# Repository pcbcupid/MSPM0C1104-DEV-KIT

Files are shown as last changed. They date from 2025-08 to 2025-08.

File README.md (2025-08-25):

# MSPM0C1104-DEV-KIT / INDUSTRIAL TEMPERATURE/HUMIDITY SENSOR MODULE WITH RS485 OUTPUT 
pcbcupid-gsense-gsi003

This design can be used as both exploration boards for worlds tiniest controller and also as a stand alone sensor module 
which can measure temperature and humidity with very high prescision. 

You can read more about it here : [link](https://learn.pcbcupid.com/boards/g-sense/hdc3020-rs485)

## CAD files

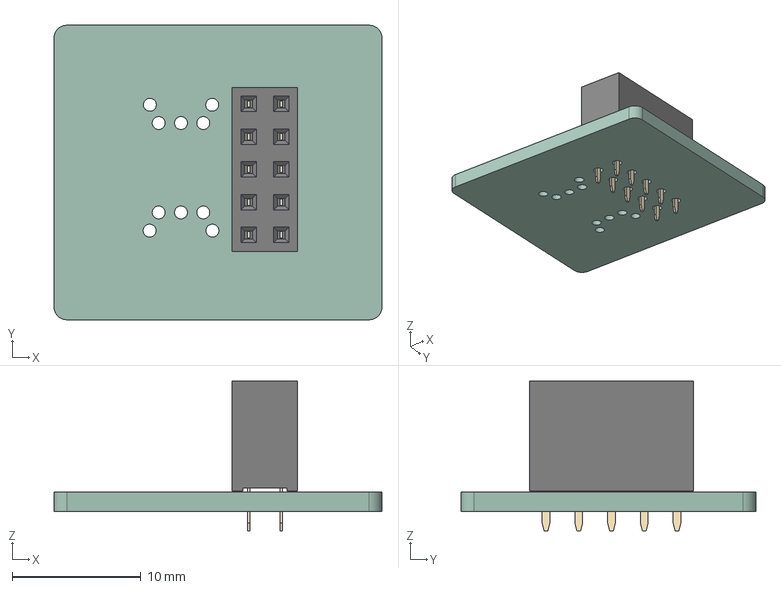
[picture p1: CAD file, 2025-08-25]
MSPM0C1104_JTAG_PROGRAMMER/MSPM0C1104_JTAG_PROGRAMMER.step
25.4 x 22.8 x 11.6 mm
PinSocket_2x05_P2.54mm_Vertical
MSPM0C_CON_PROG_V2_PCB

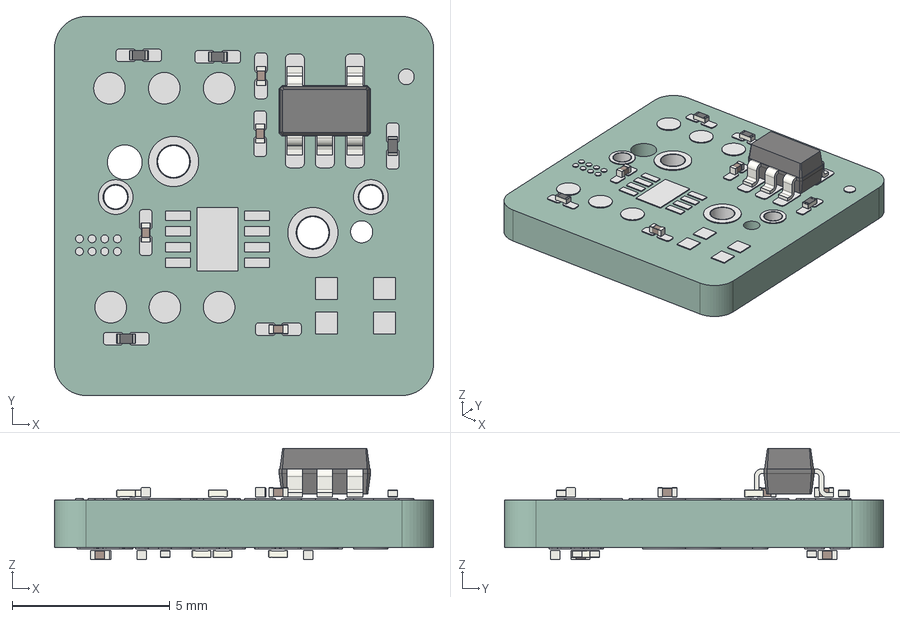
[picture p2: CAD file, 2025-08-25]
MSPMOC1104_NON-RS485-DBGA/MSPMOC1104_NON-RS485-DBGA.step
12.0 x 12.0 x 3.53 mm
C_0201_0603Metric x 8
R_0201_0603Metric x 8
SOT-23-5
MSPMOC1104_DBGA_V2_pad
MSPMOC1104_DBGA_V2_PCB

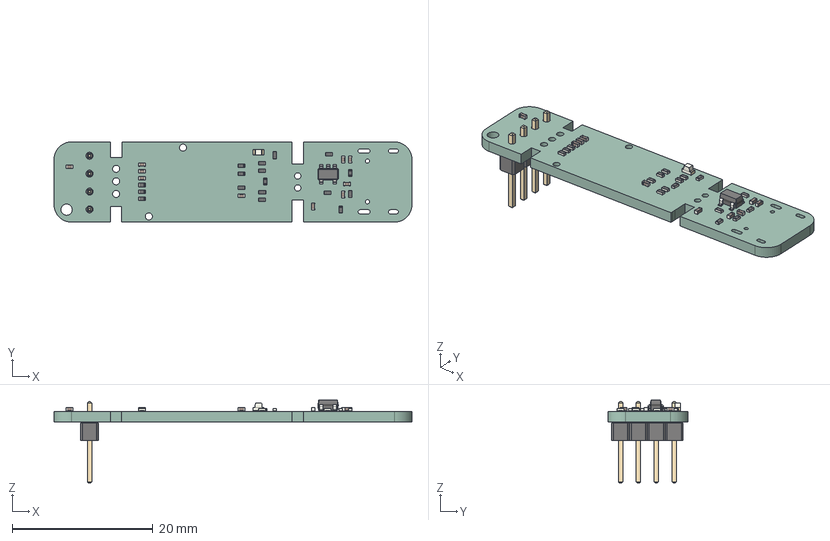
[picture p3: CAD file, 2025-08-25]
MSPMOC1104_RS485/MSPMOC1104_RS485.step
50.8 x 11.4 x 11.8 mm
R_0402_1005Metric x 17
C_0402_1005Metric x 10
LED_0603_1608Metric
SOT-23-5
PinHeader_1x04_P2.54mm_Vertical
MSPMOC1104_RS485_V2_PCB

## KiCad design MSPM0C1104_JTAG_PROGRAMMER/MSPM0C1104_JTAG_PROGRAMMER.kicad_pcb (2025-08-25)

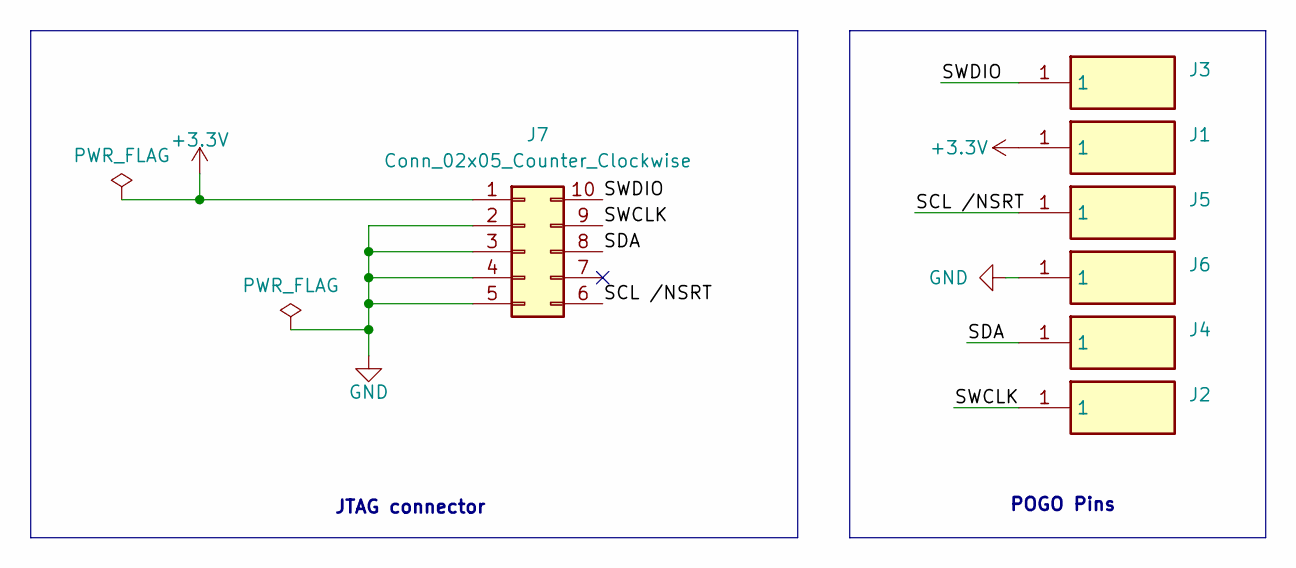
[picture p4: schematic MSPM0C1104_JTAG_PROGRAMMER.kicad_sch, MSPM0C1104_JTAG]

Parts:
J1, J2, J3, J4, J5, J6: 0950-0-15-20-64-14-11-0; TestPoint_THTPad_D1.5mm_Drill1mm; Mouser Part Number 575-950015206414110
J7: Conn_02x05_Counter_Clockwise; PinSocket_2x05_P2.54mm_Vertical

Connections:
+3.3V: J1.1, J7.1
/SCL /NSRT: J5.1, J7.6
/SDA: J4.1, J7.8
/SWCLK: J2.1, J7.9
/SWDIO: J3.1, J7.10
GND: J6.1, J7.2, J7.3, J7.4, J7.5

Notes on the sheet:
POGO Pins
JTAG connector

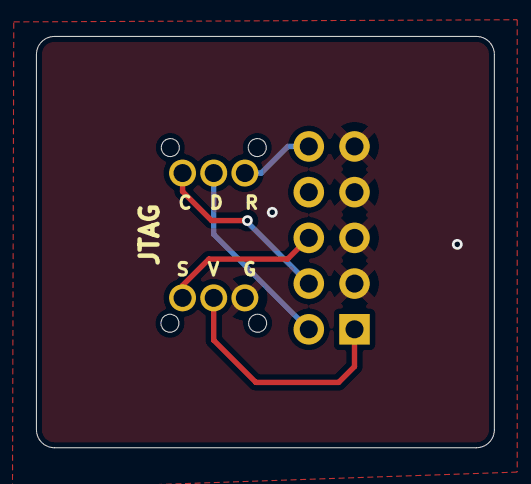
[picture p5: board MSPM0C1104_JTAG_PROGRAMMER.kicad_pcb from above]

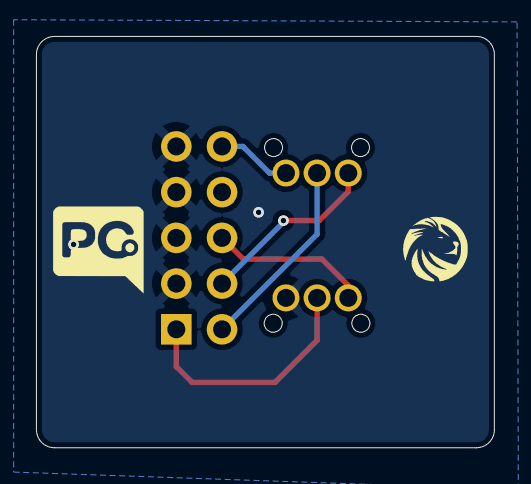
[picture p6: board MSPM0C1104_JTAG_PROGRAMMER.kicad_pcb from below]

Board: 2 copper layers, 25.4 x 22.8 mm, 7 parts (6 on the bottom side), 6 nets.

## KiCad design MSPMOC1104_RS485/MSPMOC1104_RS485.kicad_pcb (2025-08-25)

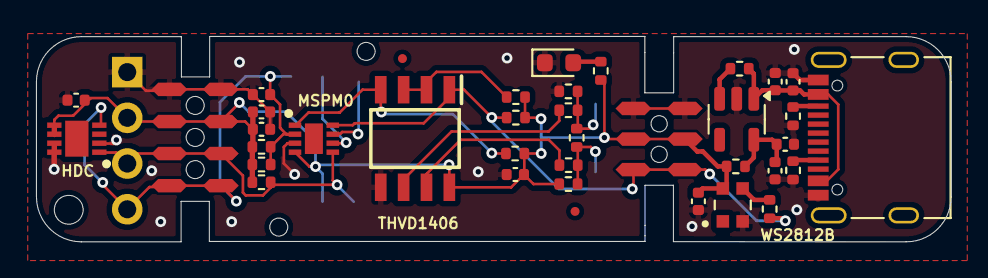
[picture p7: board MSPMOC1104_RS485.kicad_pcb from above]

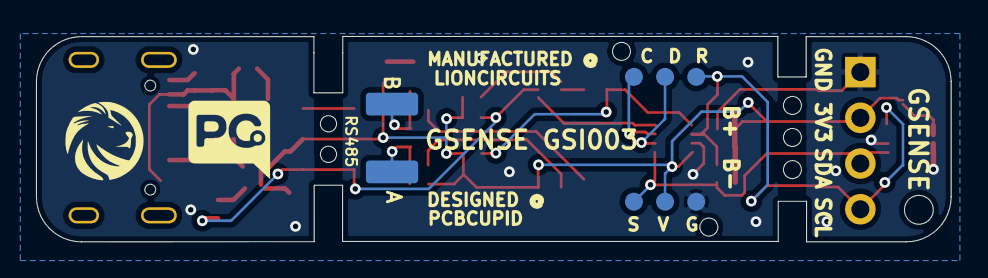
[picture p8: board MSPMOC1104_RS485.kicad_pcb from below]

Board: 2 copper layers, 50.8 x 11.4 mm, 58 parts (10 on the bottom side), 20 nets.

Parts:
C1, C2, C3, C6, C7: 0.1uF; C_0402_1005Metric
C4: 10nF; C_0402_1005Metric
C5: 10uF; C_0402_1005Metric
C8, C9, C10: 10uf; C_0402_1005Metric
D2: LED; LED_0603_1608Metric
GND: TestPoint_Pad_1.0x1.0mm
GND#2, GND#3, GND#4, GND#5, GND#6, GND#7, GND#8, GND#9, GND#10, GND#11, GND#12, GND#13, GND#14: TestPoint_Pad_1.0x1.0mm
IC1: HDC3020DEFR
IC2: THVD1426DR
J1, J2, J3, J4, J5, J6: 0950-0-15-20-64-14-11-0; TestPoint_Pad_D1.0mm
J7: USB_C_Receptacle_USB2.0_16P; USB_C_Receptacle_Palconn_UTC16-G
J8: Conn_01x02_Pin; conn_1_2
J9: Conn_01x04; PinHeader_1x04_P2.54mm_Vertical
Lion_circuits-1: LOGO; Lion_circuits_Logo
PCB_CUBID-1: LOGO; PCB_CUBID
R1: 220R; R_0402_1005Metric
R2, R3: 4.7K; R_0402_1005Metric
R4, R6: 5.1k; R_0402_1005Metric
R5: 47K; R_0402_1005Metric
R7, R8, R9, R12, R14, R17: 4.7k; R_0402_1005Metric
R10, R11: 100; R_0402_1005Metric
R13: 120E; R_0402_1005Metric
R15: 100K; R_0402_1005Metric
R16: 0R; R_0402_1005Metric
U1: WS2812-2020; LED_WS2812-2020
U2: MSPM0C1104SDSGR
U3: AP2112K-3.3v; SOT-23-5

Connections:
+3.3V: C1.1, C2.1, C3.1, C5.1, C7.1, GND.1, GND#7.1, GND#8.1, GND#10.1, IC1.5 (VDD), IC1.6 (~RESET), IC2.8 (VCC), J1.1, J9.2, R2.1, R3.1, R5.1, R7.1, R8.2, R9.1, R12.2, R16.1, R17.2, U1.4 (VDD), U2.4 (VDD)
/SCL /NSRT: C4.1, GND#11.1, GND#13.1, IC1.4 (SCL), J2.1, J9.4, R3.2, R5.2, U2.2 (PA1/NRST)
/SDA: GND#2.1, GND#14.1, IC1.1 (SDA), J6.1, J9.3, R2.2, U2.5 (PA0)
/SWCLK: J5.1, U2.7 (PA20/A6/SWCLK)
/SWDIO: J3.1, U2.6 (PA19/SWDIO)
/VBUS: C6.1, C10.1, J7.A4 (VBUS), J7.A9 (VBUS), J7.B4 (VBUS), J7.B9 (VBUS), R15.1, U3.1 (VIN)
/cc1: J7.A5 (CC1), R4.1
/cc2: J7.B5 (CC2), R6.1
/led: R1.2, U1.3 (DI)
/pa24: GND#6.1, GND#9.1, IC2.1 (R), R1.1, R9.2, U2.8 (PA24/A3)
/pa27: IC2.4 (D), R8.1, U2.1 (PA27/A0)
/padA: IC2.7 (B), R10.1
/padB: IC2.6 (A), R11.1
/pasA: J8.1, R10.2, R12.1, R13.2
/pasB: J8.2, R11.2, R13.1, R14.2
/rs: IC2.2 (~RE), IC2.3 (~SHDN), R7.2
GND: C1.2, C2.2, C3.2, C4.2, C5.2, C6.2, C7.2, C8.2, C9.2, C10.2, D2.1 (K), GND#3.1, GND#4.1, GND#5.1, GND#12.1, IC1.2 (ADDR), IC1.7 (ADDR1), IC1.8 (GND), IC2.5 (GND), J4.1, J7.A1 (GND), J7.A12 (GND), J7.B1 (GND), J7.B12 (GND), J9.1, R4.2, R6.2, R14.1, U1.2 (GND), U2.3 (VSS), U3.2 (GND)
unnamed: D2.2 (A), R17.1
unnamed: R15.2, U3.3 (EN)
unnamed: C8.1, C9.1, R16.2, U3.5 (VOUT)

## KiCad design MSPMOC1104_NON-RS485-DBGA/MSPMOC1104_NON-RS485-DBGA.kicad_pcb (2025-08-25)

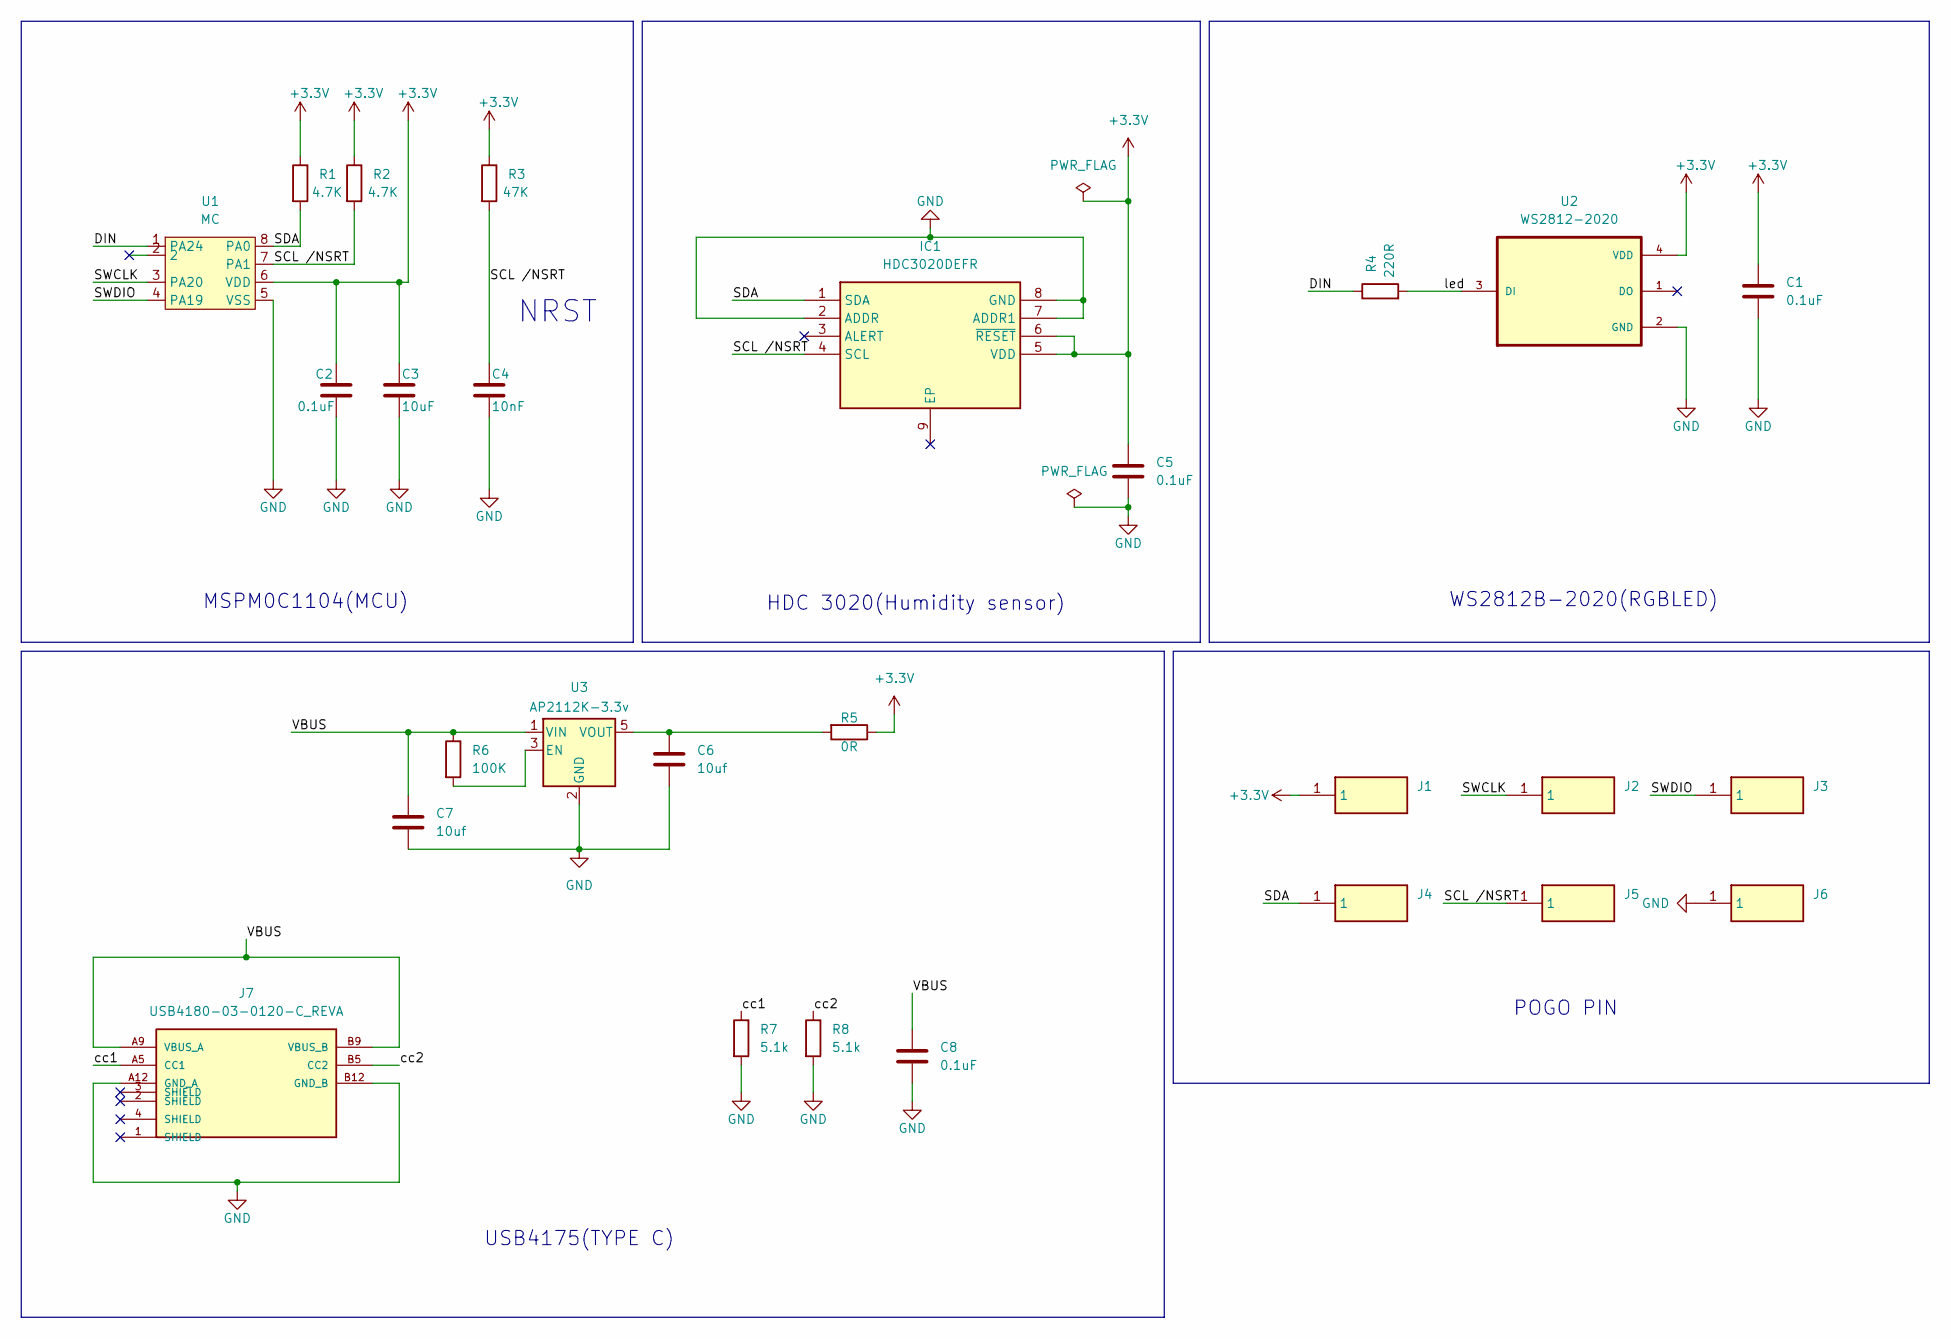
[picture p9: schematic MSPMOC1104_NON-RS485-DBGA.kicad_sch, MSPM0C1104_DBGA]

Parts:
C1, C2, C5, C8: 0.1uF; C_0201_0603Metric_Pad0.64x0.40mm_HandSolder
C3: 10uF; C_0201_0603Metric_Pad0.64x0.40mm_HandSolder
C4: 10nF; C_0201_0603Metric_Pad0.64x0.40mm_HandSolder
C6, C7: 10uf; C_0201_0603Metric_Pad0.64x0.40mm_HandSolder
IC1: HDC3020DEFR; Mouser Part Number 595-HDC3020DEFR
J1, J2, J3, J4, J5, J6: 0950-0-15-20-64-14-11-0; TestPoint_Pad_D1.0mm; Mouser Part Number 575-950015206414110
J7: USB4180-03-0120-C_REVA; USB4180030120C; PARTREV A; DigiKey_Part_Number 2073-USB4180-03-0120-CTR-ND
R1, R2: 4.7K; R_0201_0603Metric_Pad0.64x0.40mm_HandSolder
R3: 47K; R_0201_0603Metric_Pad0.64x0.40mm_HandSolder
R4: 220R; R_0201_0603Metric_Pad0.64x0.40mm_HandSolder
R5: 0R; R_0201_0603Metric_Pad0.64x0.40mm_HandSolder
R6: 100K; R_0201_0603Metric_Pad0.64x0.40mm_HandSolder
R7, R8: 5.1k; R_0201_0603Metric_Pad0.64x0.40mm_HandSolder
U1: MC; MCU_TI_MSPM0C1104
U2: WS2812-2020; LED_WS2812-2020; PARTREV V1.3
U3: AP2112K-3.3v; SOT-23-5

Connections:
+3.3V: C1.1, C2.1, C3.1, C5.1, IC1.5 (VDD), IC1.6 (~RESET), J1.1, R1.1, R2.1, R3.1, R5.1, U1.6 (VDD), U2.4 (VDD)
/DIN: R4.1, U1.1 (PA24)
/SCL /NSRT: C4.1, IC1.4 (SCL), J5.1, R2.2, R3.2, U1.7 (PA1)
/SDA: IC1.1 (SDA), J4.1, R1.2, U1.8 (PA0)
/SWCLK: J2.1, U1.3 (PA20)
/SWDIO: J3.1, U1.4 (PA19)
/VBUS: C7.1, C8.1, J7.A9 (VBUS_A), J7.B9 (VBUS_B), R6.1, U3.1 (VIN)
/cc1: J7.A5 (CC1), R7.1
/cc2: J7.B5 (CC2), R8.1
/led: R4.2, U2.3 (DI)
GND: C1.2, C2.2, C3.2, C4.2, C5.2, C6.2, C7.2, C8.2, IC1.2 (ADDR), IC1.7 (ADDR1), IC1.8 (GND), J6.1, J7.A12 (GND_A), J7.B12 (GND_B), R7.2, R8.2, U1.5 (VSS), U2.2 (GND), U3.2 (GND)
unnamed: R6.2, U3.3 (EN)
unnamed: C6.1, R5.2, U3.5 (VOUT)

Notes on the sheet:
POGO PIN
USB4175(TYPE C)
NRST
HDC 3020(Humidity sensor)
WS2812B-2020(RGBLED)
MSPM0C1104(MCU)

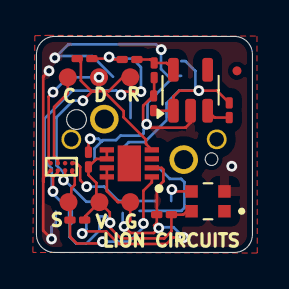
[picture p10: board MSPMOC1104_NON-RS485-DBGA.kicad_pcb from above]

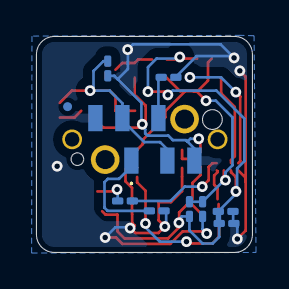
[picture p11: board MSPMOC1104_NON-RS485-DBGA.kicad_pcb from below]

Board: 2 copper layers, 12.0 x 12.0 mm, 27 parts (9 on the bottom side), 13 nets.

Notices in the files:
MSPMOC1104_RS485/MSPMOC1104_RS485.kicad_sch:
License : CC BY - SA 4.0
